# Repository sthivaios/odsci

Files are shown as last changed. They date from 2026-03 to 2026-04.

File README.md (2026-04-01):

# ODSCI

<div align="center">
  
  
  <h2 style="font-weight: bold;">An STM32-based USB interface for DS18B20 temperature sensors</h2>
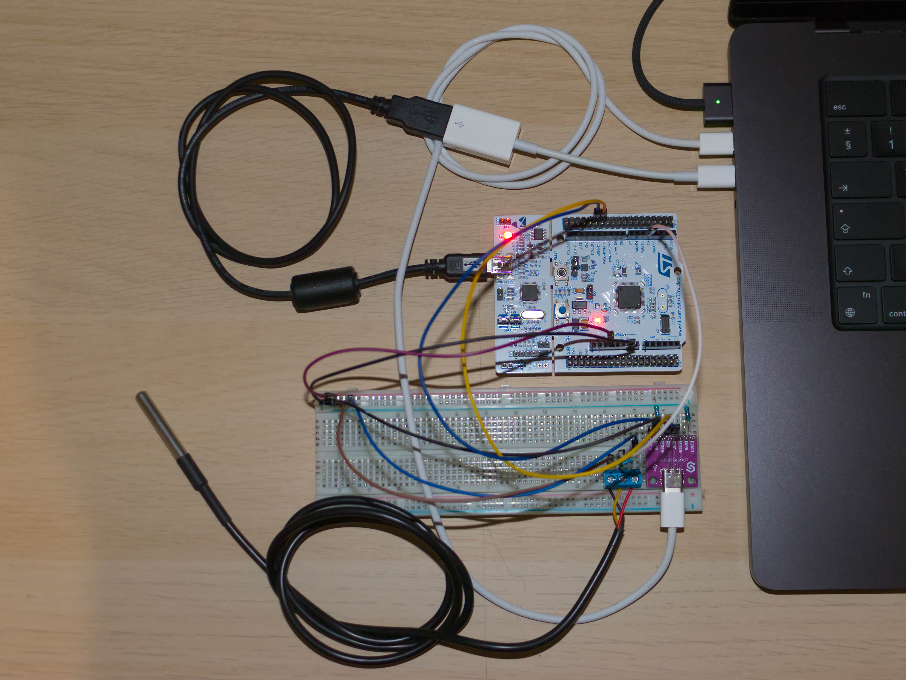
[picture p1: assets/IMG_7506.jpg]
A picture taken during the very early development of ODSCI showing an STM32 Nucleo board and a breadboard connected to a MacBook Pro
  
</div>

## Getting Started - How to use ODSCI

**If you want to get started using ODSCI quickly, and don't care about the project, this is the only section of the README that matters to you.**

You can grab a pre-built CLI binary from the releases page for your platform/OS, or build from source. The CLI is written in Go and is located in the `/cli` directory.

Connect the ODSCI probe to your computer, and find the serial port that it uses (COM port on Windows, or a /dev/tty device on Linux and MacOS).

Then, you can use the `capture` command to save a given amount of samples as a CSV file.

```shell
./odsci --port THE_SERIAL_PORT_HERE --samples 100 --interval 10 --output "./output.csv"
```

The CLI has more features than just the `capture` command. Run `./odsci --help` for more information on the commands, or read the documentation.

## Introduction

ODSCI is an STM32-based USB interface for DS18B20 sensors. It stands for **O**neWire **DS**18B20 **C**omputer **I**nterface.

It connects to any computer through a USB-C port and exposes a USB CDC virtual serial port, through which
the MCU can send temperature readings back to the computer.

I am mainly working on this project, in order to teach myself Go (which the CLI uses), while also using it as
an excuse to attempt to write my own OneWire "driver" for the STM32 to communicate with the sensor.

## Project structure

You can find each "part" of ODSCI in its corresponding folder.

1. The firmware that runs on the STM32 is written in C and configured with CubeMX and uses CMake. It is located in the `/firmware` directory.

2. The hardware (PCB) is a KiCad project. It is located under `/hardware`.

3. The enclosure was designed in Fusion360. The project file, as well as any STL exports are located under the `/enclosure`.

4. The CLI is written in Go. You can find its source under `/cli`. I will attempt to cross-compile it for different platforms. Check the repo releases for pre-built binaries.

5. The docs are written with VitePress. You can find them under `/docs`.

## Contributing

You are welcome to report any issues that you find with any part of ODSCI, or open pull requests to fix them.

If you are actually contributing code to the project, make sure that you understand the license terms.

## Licensing

Different parts of the project are licensed under different licenses.

Under each directory, you will find a separate LICENSE file for that part of the project.

While that may seem a little confusing at first, please understand that some parts like the PCB simply
aren't very compatible with the usual licenses like MIT, GPL, etc.

See [LICENSE](LICENSE) for more info.

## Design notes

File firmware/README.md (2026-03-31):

# ODSCI Firmware

## Supported hardware

### MCU
As of March 31st 2026, the current versions of the firmware are written for the Arm® Cortex-M4 platform, more specifically, the STM32F446RET6, as I am using a NUCLEO-F446RE development board.

The first revision of the hardware (v2.x), uses the STM32F042K6T6, which is based on the Arm® Cortex-M0 architecture.

The firmware will therefore require porting, in order to be able to run on the custom ODSCI hardware.

However, again, as of now, the supported hardware is the STM32F446RET6.

### Sensor (DS18B20)
Aside from the obvious (the microprocessor), the only supported sensor at the moment is the DS18B20 from Analog Devices. You can use any pre-built sensor probe that uses this sensor, such as this one from Adafruit: https://www.adafruit.com/product/381/.

Note that you can extend the cable of course as long as you'd like, since the sensor is digital, so it shouldn't affect connectivity with the ODSCI board, especially since the firmware performs CRC8 data validation to ensure that the data is not corrupted by noise on the data line.

## Flashing instructions
The ODSCI board has a DFU button. Hold this button down while plugging the board in, in order to enter the DFU mode. You can release the button once plugged in.

You can then use any tool that lets you flash a binary via DFU. I recommend `dfu-util`. In the future, if I have enough time, as I'm currently quite busy with school, I might work on a way to update the firmware on the board directly through the ODSCI CLI, so that no external tools are required.

If you do use `dfu-util`, you should use it as follows:

```shell
dfu-util -a 0 -s 0x08000000:leave -D odsci-firmware-v1.1.0-arm-cortex-m4-stm32f446re.bin
```

where, of course, instead of this file, you would have the filename of the binary that you are flashing. You can download the latest firmware binary from the releases page of the repository on GitHub, which is probably where you are reading this right now.

Otherwise, you can, of course, always use tools such as the official **STM32CubeProg from ST**, the programming software from Segger, or anything else.

## Building from source
If you wish to build the firmware from source, clone the repository, and enter the `/firmware` directory.

Then, configure and build the project with CMake as follows:

```shell
cmake -S . --preset Release
cmake --build build --preset Release
```

You can then find the binary or the .hex file in `./build/Release/`.

## Compatibility and changelog

**For the changelog (only for the firmware changelog!), see [CHANGELOG.md](CHANGELOG.md).**

### Compatibility
Nothing to see here yet, I'll add a table soon once new features are added, and the CLI requires a specific firmware version to utilize those features.

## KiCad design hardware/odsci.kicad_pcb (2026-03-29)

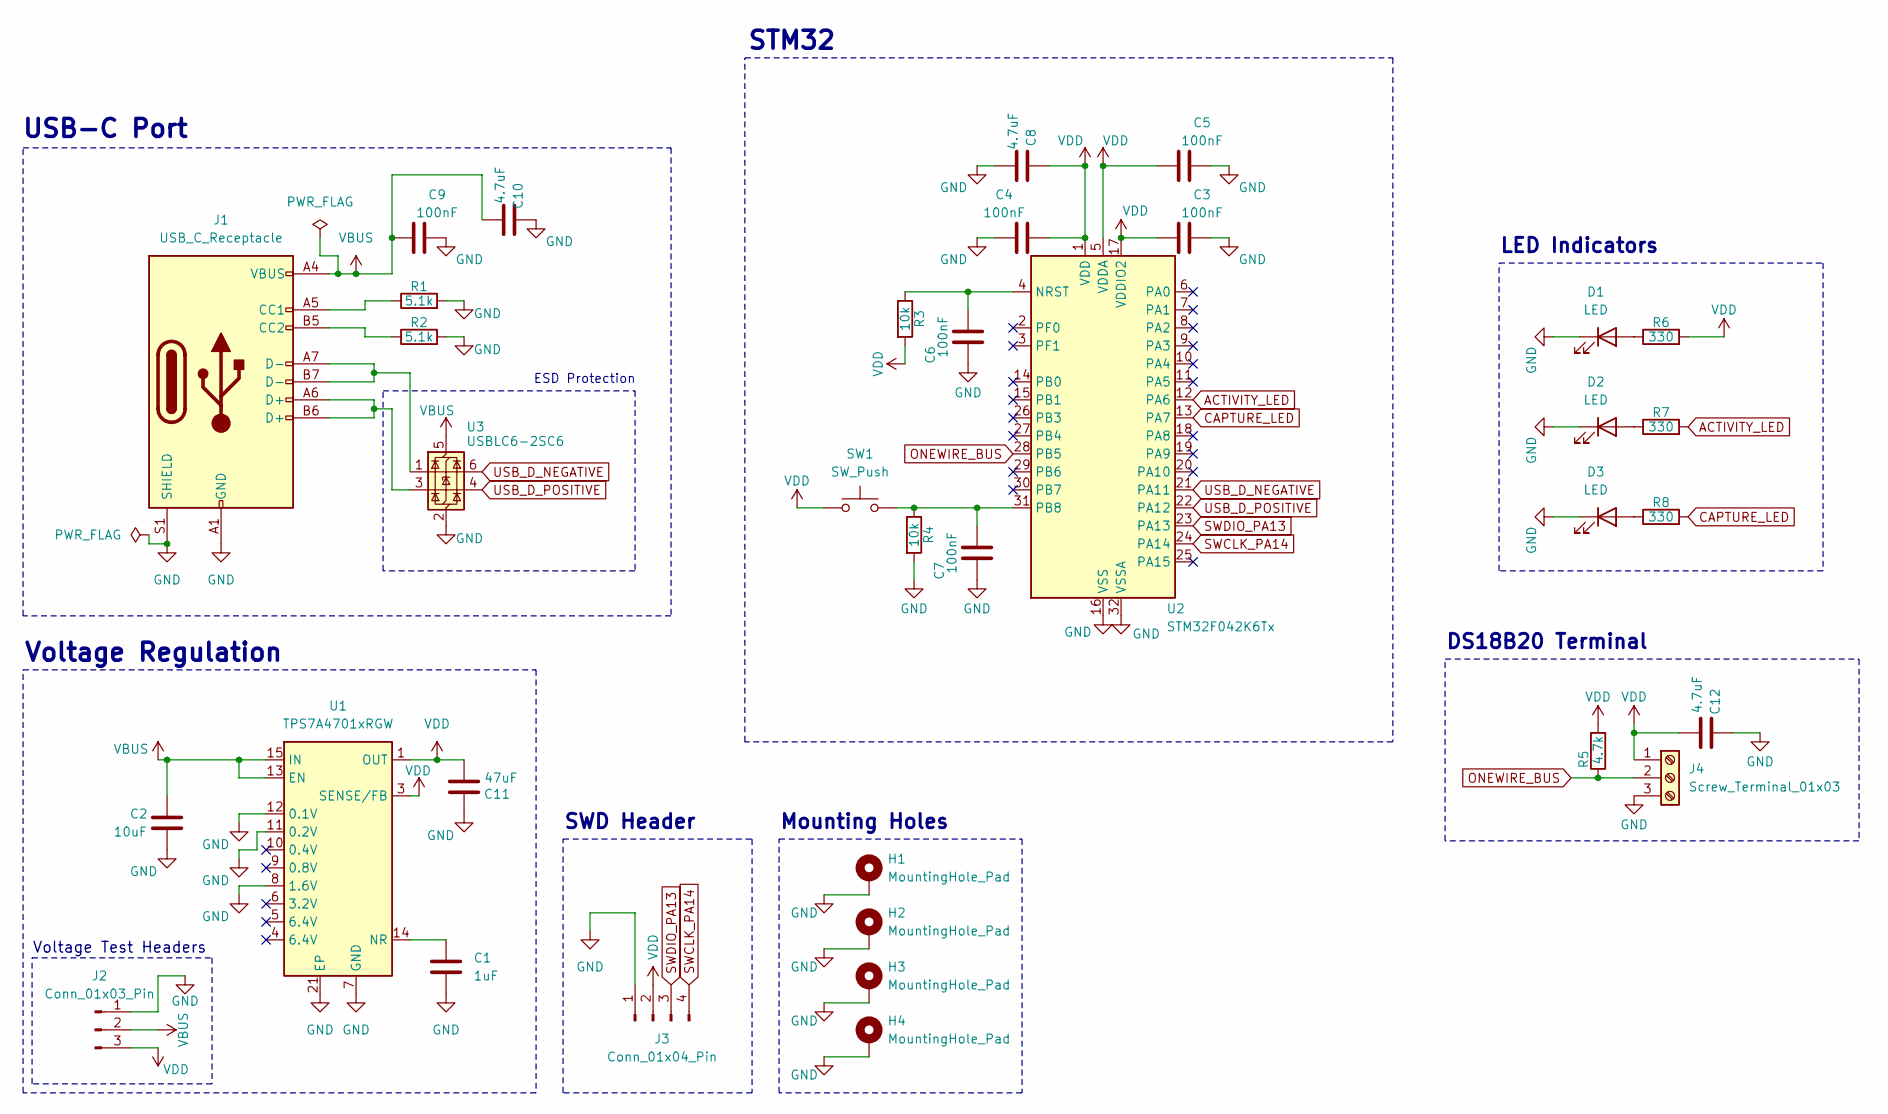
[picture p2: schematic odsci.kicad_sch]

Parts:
C1: 1uF; C_0805_2012Metric; LCSC C28323
C2: 10uF; C_0805_2012Metric; LCSC C15850
C3, C4, C5, C6, C7, C9: 100nF; C_0402_1005Metric; LCSC C1525
C8, C10, C12: 4.7uF; C_0805_2012Metric; LCSC C1779
C11: 47uF; C_0805_2012Metric; LCSC C16780
D1, D2, D3: LED; LED_D3.0mm
H1, H2, H3, H4: MountingHole_Pad; MountingHole_2.2mm_M2_Pad
J1: USB_C_Receptacle; USB_C_Receptacle_GCT_USB4105-xx-A_16P_TopMnt_Horizontal; LCSC C3020560
J2: Conn_01x03_Pin; PinHeader_1x03_P2.54mm_Vertical; LCSC C2915006
J3: Conn_01x04_Pin; PinHeader_1x04_P2.54mm_Vertical; LCSC C5184785
J4: Screw_Terminal_01x03; TerminalBlock_Phoenix_MPT-0,5-3-2.54_1x03_P2.54mm_Horizontal; LCSC C5288763
R1, R2: 5.1k; R_0402_1005Metric; LCSC C25905
R3, R4: 10k; R_0402_1005Metric; LCSC C25744
R5: 4.7k; R_0402_1005Metric; LCSC C25900
R6, R7, R8: 330; R_0402_1005Metric; LCSC C25104
SW1: SW_Push; SW_SPST_Omron_B3F-315x_Angled; LCSC C231320
U1: TPS7A4701xRGW; Texas_RGW0020A_VQFN-20-1EP_5x5mm_P0.65mm_EP3.15x3.15mm_Ther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; LCSC C90084
U2: STM32F042K6Tx; LQFP-32_7x7mm_P0.8mm; LCSC C69216
U3: USBLC6-2SC6; SOT-23-6; LCSC C7519

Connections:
ACTIVITY_LED: R7.2, U2.12 (PA6)
CAPTURE_LED: R8.2, U2.13 (PA7)
GND: C1.1, C2.1, C3.1, C4.1, C5.1, C6.2, C7.2, C8.1, C9.1, C10.2, C11.2, C12.2, D1.1 (K), D2.1 (K), D3.1 (K), H1.1, H2.1, H3.1, H4.1, J1.A1 (GND), J1.A12 (GND), J1.B1 (GND), J1.B12 (GND), J1.S1 (SHIELD), J2.1, J3.1, J4.3, R1.2, R2.2, R4.2, U1.7 (GND), U1.8 (1.6V), U1.11 (0.2V), U1.12 (0.1V), U1.21 (EP), U2.16 (VSS), U2.32 (VSSA), U3.2 (GND)
unnamed: D1.2 (A), R6.1
unnamed: D2.2 (A), R7.1
unnamed: D3.2 (A), R8.1
unnamed: J1.A5 (CC1), R1.1
unnamed: J1.B5 (CC2), R2.1
unnamed: J1.A6 (D+), J1.B6 (D+), U3.3 (I/O2)
unnamed: J1.A7 (D-), J1.B7 (D-), U3.1 (I/O1)
unnamed: C1.2, U1.14 (NR)
unnamed: C6.1, R3.1, U2.4 (NRST)
unnamed: C7.1, R4.1, SW1.2, U2.31 (PB8)
ONEWIRE_BUS: J4.2, R5.1, U2.28 (PB5)
SWCLK_PA14: J3.4, U2.24 (PA14)
SWDIO_PA13: J3.3, U2.23 (PA13)
USB_D_NEGATIVE: U2.21 (PA11), U3.6 (I/O1)
USB_D_POSITIVE: U2.22 (PA12), U3.4 (I/O2)
VBUS: C2.2, C9.2, C10.1, J1.A4 (VBUS), J1.A9 (VBUS), J1.B4 (VBUS), J1.B9 (VBUS), J2.2, U1.13 (EN), U1.15 (IN), U1.16 (IN), U3.5 (VBUS)
VDD: C3.2, C4.2, C5.2, C8.2, C11.1, C12.1, J2.3, J3.2, J4.1, R3.2, R5.2, R6.2, SW1.1, U1.1 (OUT), U1.3 (SENSE/FB), U1.20 (OUT), U2.1 (VDD), U2.5 (VDDA), U2.17 (VDDIO2)

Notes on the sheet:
STM32
ESD Protection
USB-C Port
Voltage Regulation
Voltage Test Headers
LED Indicators
SWD Header
Mounting Holes
DS18B20 Terminal

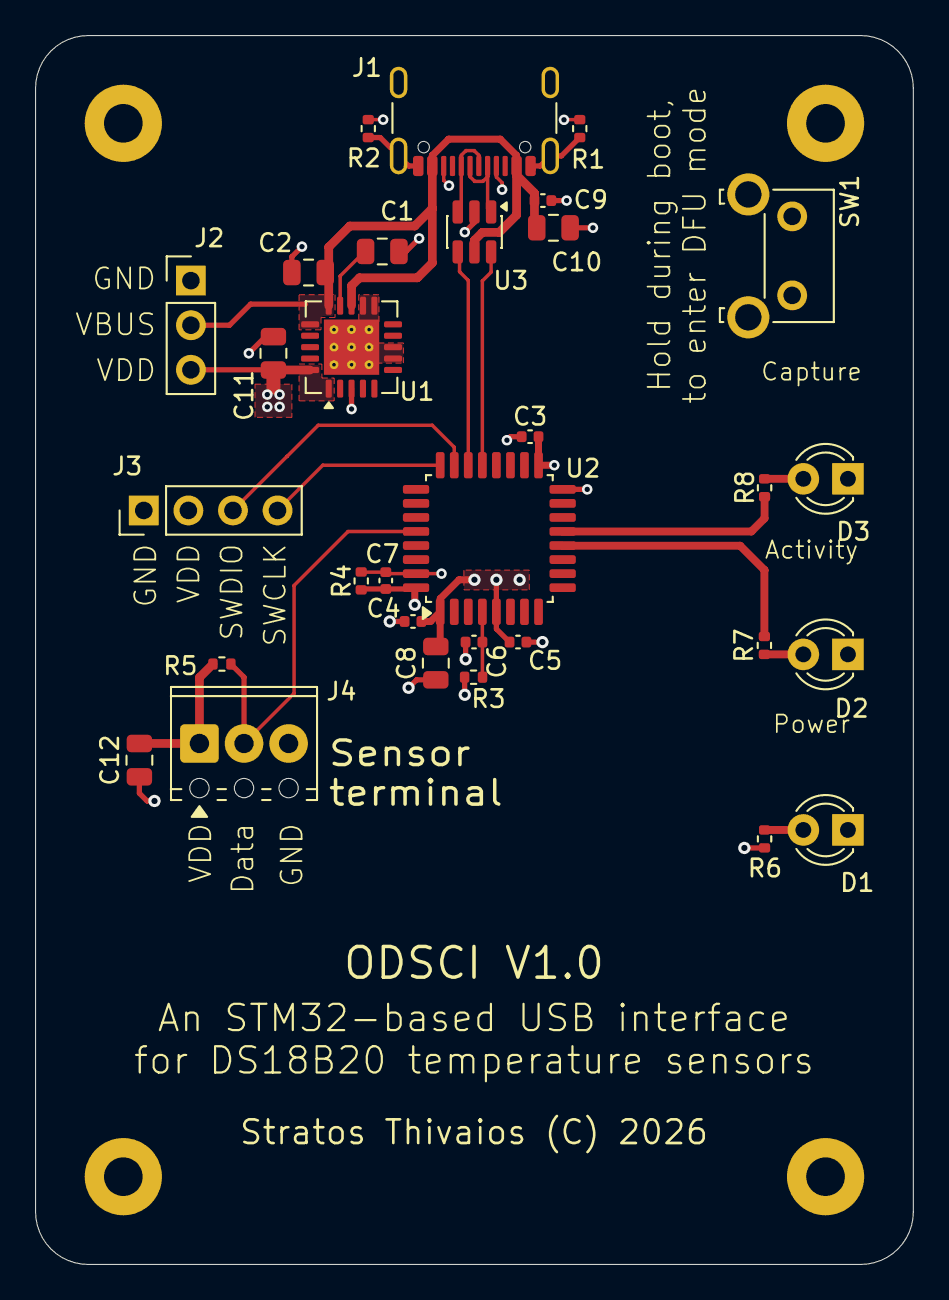
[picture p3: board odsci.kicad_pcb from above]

Board: 4 copper layers, 50.0 x 70.0 mm, 35 parts (0 on the bottom side), 20 nets.

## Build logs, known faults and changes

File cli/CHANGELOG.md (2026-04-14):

# Changelog (for the ODSCI CLI only)

Note: Changelog started at v1.0.0. See commit history for changes prior to this version.

## Unreleased

### Added
- Added the `--silence-advisories` flag to... well... silence advisories
- The capture command now informs the user at the end about how many samples were actually valid and written to the file

## [v1.2.0] - 2026-04-07

### Added

- Added the ability to use ISO 8601 instead of UNIX timestmaps in the CSV output of the `capture` command
- Added the ability to select a unit of measurement in the `read` command with the `--unit` or `-u` flag
- The `capture` command now stores values in degrees Celsius, Fahrenheit and Kelvin in the CSV in separate columns
- The `read` command now shows the difference from the last read, next to the value
- All commands that communicate with the board, now print an advisory if the last reset reason was an IWDG timeout
- All commands that communicate with the board, now print an advisory if the sensor CRC8 data validation fails

### Fixed

- Fixed minor bug where the capture command would attempt to turn on the CLED without checking the flag first
- Fixed major bug where the `read` command wouldn't actually update because it was only reading the temperature once

### Changed

- Major improvements to error handling
- Updated from v1.0.0 of the schollz/progressbar library, to v3
- Updated the way that the GET_INFO command result is decoded

## [v1.1.1] - 2026-03-31

### Fixed

- The `read` and `capture` commands, now require the `--port` and `--output` flags where applicable.

## [v1.1.0] - 2026-03-31

### Added

- Added the `read` command

### Changed

- Capture command checks firmware CLED flag before sending CLED commands; see PR #6

### Fixed

- Fixed a bug where the first temperature reading would fail because the serial buffer wasn't cleared
- Improved error handling in mulitple functions

## [v1.0.0] - 2026-03-29

### Added

- Added the `version` command to print the version string

### Breaking Changes

- Removed the `scan` command

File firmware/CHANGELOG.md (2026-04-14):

# Changelog (for the ODSCI firmware only)
 
Note: Changelog started at v1.1.0. See commit history for changes prior to this version.

## [v2.0.1] - 2026-04-15

### Fixed
- IWDG timeout was too short, causing ODSCI to enter a loop after reading the temperature where it would reboot because the conversion took too long

## [v2.0.0] - 2026-04-14

### Beraking Changes
- Ported the firmware from the ARM® Cortex-M4 platform to the ARM® Cortex-M0 platform, for the STM32F042K6T6 MCU present on V1 of the ODSCI hardware

## [v1.2.0] - 2026-04-07

### Added
- Configured the IWDG to timeout after 2000ms

### Changed
- The GET_INFO command now also returns the serial number and whether the last reset reason was an IWDG timeout
- The serial number of the device as well as the USB descriptor serial is derived from a new function in command_handler.c
- Updated the USB device descriptors (product string, manufacturer, etc.)

### Fixed
- Fixed a minor bug in the main firmware loop, that could potentially cause a race condition
- Improved error handling when getting the temperature
- Improved error handling when the command buffer overflows

## [v1.1.0] - 2026-03-29

### Added
- CRC validation on DS18B20 scratchpad readings

### Breaking Changes
- CAPTURE_LED now used as error indicator, SET_CLED_ON and SET_CLED_OFF removed in this mode

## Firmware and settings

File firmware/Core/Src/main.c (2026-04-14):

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
/* Includes ------------------------------------------------------------------*/
#include "main.h"
#include "usb_device.h"

/* USER CODE BEGIN Includes */
#include "../../App/Inc/led_control.h"
/* USER CODE END Includes */

IWDG_HandleTypeDef hiwdg;

TIM_HandleTypeDef htim2;

/* USER CODE BEGIN PV */

TakeAction_Params_T TakeAction_ClearStruct;
volatile TakeAction_Params_T TakeAction_Params;
volatile bool LastResetDueToIWDG;
/* USER CODE END PV */

void SystemClock_Config(void);
static void MX_GPIO_Init(void);
static void MX_TIM2_Init(void);
static void MX_IWDG_Init(void);
/* USER CODE BEGIN 0 */

void change_takeAction_params(const TakeAction_Params_T params) {
  TakeAction_Params = params;
}
/* USER CODE END 0 */

/**
  * @brief  The application entry point.
  * @retval int
  */
int main(void)
{

  /* MCU Configuration--------------------------------------------------------*/

  /* Reset of all peripherals, Initializes the Flash interface and the Systick. */
  HAL_Init();

  /* Configure the system clock */
  SystemClock_Config();

  /* Initialize all configured peripherals */
  MX_GPIO_Init();
  MX_USB_DEVICE_Init();
  MX_TIM2_Init();
  MX_IWDG_Init();
  /* USER CODE BEGIN 2 */

  // check reset cause before anything else
  set_last_reset_due_to_iwdg(__HAL_RCC_GET_FLAG(RCC_FLAG_IWDGRST));
  if (__HAL_RCC_GET_FLAG(RCC_FLAG_IWDGRST)) {
    int i = 0;
    while (i < 6) {
      HAL_GPIO_WritePin(CLED_OR_ERROR_LED_GPIO_Port, CLED_OR_ERROR_LED_Pin, true);
      HAL_Delay(350);
      HAL_GPIO_WritePin(CLED_OR_ERROR_LED_GPIO_Port, CLED_OR_ERROR_LED_Pin, false);
      HAL_Delay(250);
      HAL_IWDG_Refresh(&hiwdg);
      i = i + 1;
    }
  }
  __HAL_RCC_CLEAR_RESET_FLAGS(); // clear them for next time

  // start the timer
  HAL_TIM_Base_Start(&htim2);
  /* USER CODE END 2 */

  /* Infinite loop */
  /* USER CODE BEGIN WHILE */
  // ReSharper disable once CppDFAEndlessLoop
  while (1) {
    // disable interrupts to prevent a race condition if the usb interrupt tries to access the var too
    __disable_irq();
    // before clearing the var, we store the value in a new var to pass it to the take_action() func
    const TakeAction_Params_T local_params = TakeAction_Params;
    TakeAction_Params = TakeAction_ClearStruct;
    // enable the interrupts again
    __enable_irq();

    // now actually take action
    take_action(local_params);


    HAL_IWDG_Refresh(&hiwdg);
    HAL_Delay(1);
  }
    /* USER CODE END WHILE */

}

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


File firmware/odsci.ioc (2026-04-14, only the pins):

Mcu.UserName=STM32F042K6Tx
PA11.Signal=USB_DM
PA12.Signal=USB_DP
PA13.Signal=SYS_SWDIO
PA14.Signal=SYS_SWCLK
PA6.GPIO_Label=ACTIVITY_LED
PA6.Signal=GPIO_Output
PA7.GPIO_Label=CLED_OR_ERROR_LED
PA7.Signal=GPIO_Output
PB5.GPIO_Label=ONEWIRE_BUS
PB5.Signal=GPIO_Input

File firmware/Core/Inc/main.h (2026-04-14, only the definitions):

#define ACTIVITY_LED_Pin GPIO_PIN_6
#define ACTIVITY_LED_GPIO_Port GPIOA
#define CLED_OR_ERROR_LED_Pin GPIO_PIN_7
#define CLED_OR_ERROR_LED_GPIO_Port GPIOA
#define ONEWIRE_BUS_Pin GPIO_PIN_5
#define ONEWIRE_BUS_GPIO_Port GPIOB

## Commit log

2026-03-18 add onewire driver
2026-03-18 fix dumb include issues
    [main.c, onewire.c]
2026-03-18 try to read the sensor in main.c
2026-03-18 make temperature variable global
2026-03-20 configure PA6 and PA7 for leds
2026-03-20 change led labels in mx
2026-03-20 led control
2026-03-21 hardware: init kicad project
    [odsci.kicad_pcb, odsci.kicad_sch]
2026-03-21 hardware: schematic completed
    [odsci.kicad_sch]
2026-03-21 hardware: route pcb
    [odsci.kicad_pcb, odsci.kicad_sch]
2026-03-21 hardware: add mounting holes to pcb
    [odsci.kicad_pcb, odsci.kicad_sch]
2026-03-22 hardware: add a few decoupling caps
    [odsci.kicad_pcb, odsci.kicad_sch]
2026-03-22 hardware: layout of pcb
    [odsci.kicad_pcb]
2026-03-22 hardware: fix mounting hole positions
    [odsci.kicad_pcb]
2026-03-22 hardware: fully reroute and change pcb's layout
    [odsci.kicad_pcb, odsci.kicad_sch]
2026-03-24 hardware: update silkscreen, tiny layout changes
    [odsci.kicad_pcb]
2026-03-24 hardware and schematic: add LCSC part number for switch
    [odsci.kicad_pcb, odsci.kicad_sch]
2026-03-24 hardware and schematic: update USB-C connector LCSC part number
    [odsci.kicad_pcb, odsci.kicad_sch]
2026-03-25 hardware: fix position of LEDs on the pcb to match enclosure
    [odsci.kicad_pcb]
2026-03-28 hardware and schematic: update STM32 LCSC part number
    [odsci.kicad_pcb, odsci.kicad_sch]
2026-03-29 use error indicator in different places
    [led_control.c]
2026-03-29 ci/cd: im gonna die lmao
2026-03-31 cli: board info check function
2026-04-01 firmware: fix minor bug that could cause a race condition
    [main.c]
2026-04-02 cli: `read` cmd: format to string propely before printing output
2026-04-02 cli: read cmd: print unit too
2026-04-02 cli: read cmd: fix bug where temperature wouldnt update with the --watch flag
2026-04-03 firmware: improve error handling when getting temperature
    [onewire.c]
2026-04-05 cli: read cmd: fix multiple bugs with the temperature conversion
2026-04-06 cli: detect iwdg reset and print advisory
2026-04-06 cli: decode serial string too in board check
2026-04-06 cli: iwdg advisory: print actual serial number
2026-04-06 cli: change board check info decode approach
2026-04-07 CLI: print CRC errors and advisories in read and capture cmds
2026-04-14 firmware: cleanup and replace files with their stm32f0 equivalent
    [main.c, main.h, odsci.ioc]
2026-04-14 cli: add the silence-advisories flag, inform user about amount of valid samples captured, update changelog

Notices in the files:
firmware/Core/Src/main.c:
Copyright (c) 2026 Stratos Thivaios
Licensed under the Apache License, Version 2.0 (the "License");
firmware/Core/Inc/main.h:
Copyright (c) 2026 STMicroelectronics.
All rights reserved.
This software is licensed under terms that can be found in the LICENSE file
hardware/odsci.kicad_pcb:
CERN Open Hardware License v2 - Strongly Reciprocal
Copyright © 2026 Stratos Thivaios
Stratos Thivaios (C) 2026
